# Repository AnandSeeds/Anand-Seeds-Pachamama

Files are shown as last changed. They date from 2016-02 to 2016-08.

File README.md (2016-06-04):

# Sistema de versionamiento AnandSeeds
## Proyecto Piloto - [SIE (Sistema de Innovación Ecológico) Cultivando Futuro!!!](http://anandseeds.co/index.php) 

Desarrollamos e implementamos soluciones TI relacionadas con IoT (Internet of Things), Big Data y Cloud Computing dirigidas al sector agropecuario y agroindustrial. Anand Seeds le permite crear una red de monitoreo integral de los parámetros agroclimáticos para alertar eventos y garantizar mejores cosechas. En nuestro equipo, entendemos que los problemas de cada productor son distintos y es por eso que trabajamos en entregar un set de información integral para el desarrollo del cultivo.

## Hardware Top
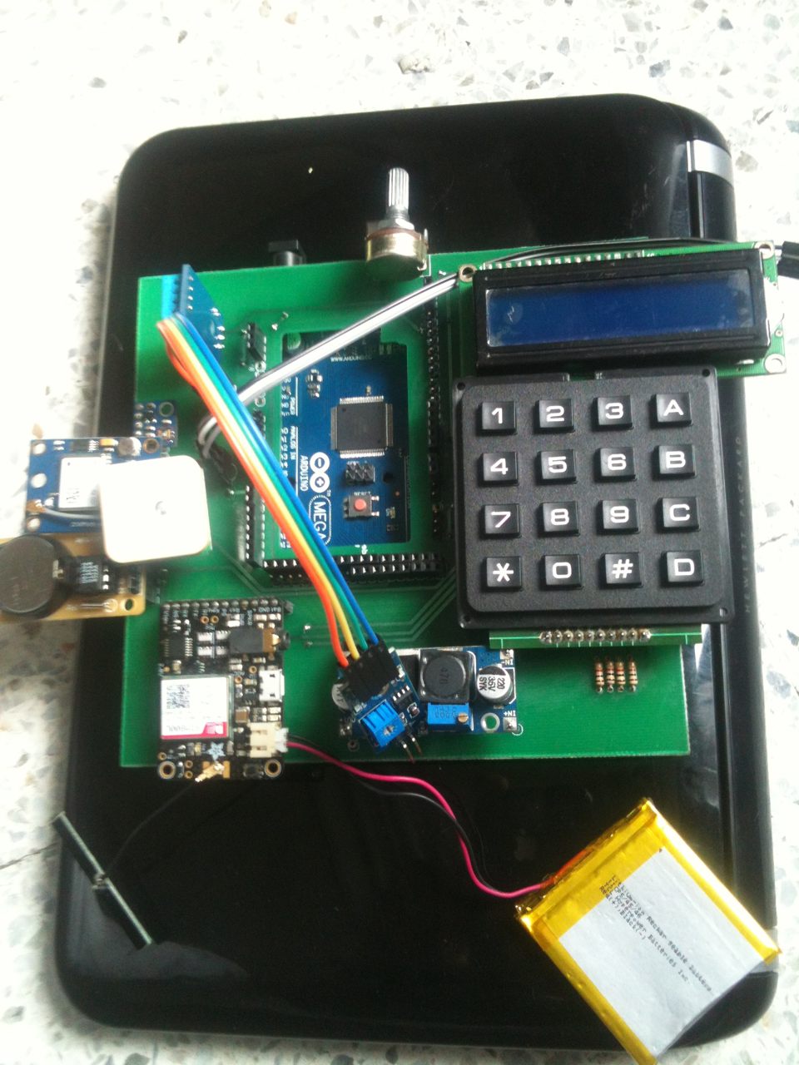
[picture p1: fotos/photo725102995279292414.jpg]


## Hardware Bottom
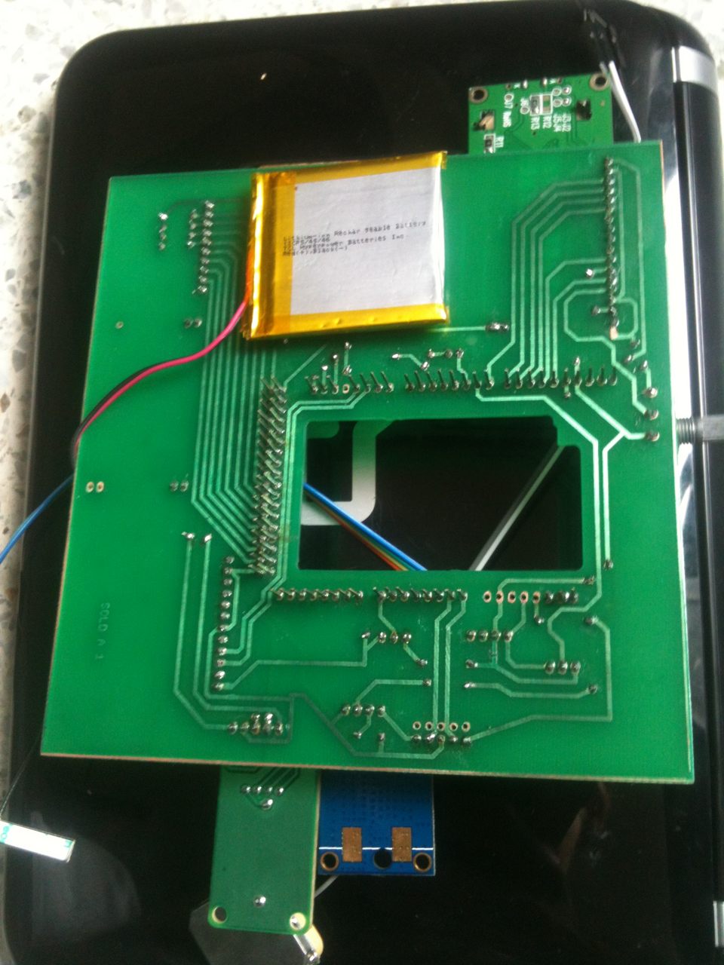
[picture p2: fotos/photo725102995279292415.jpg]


### INFORMACIÓN DE CONTACTO DESARROLLADORES ###
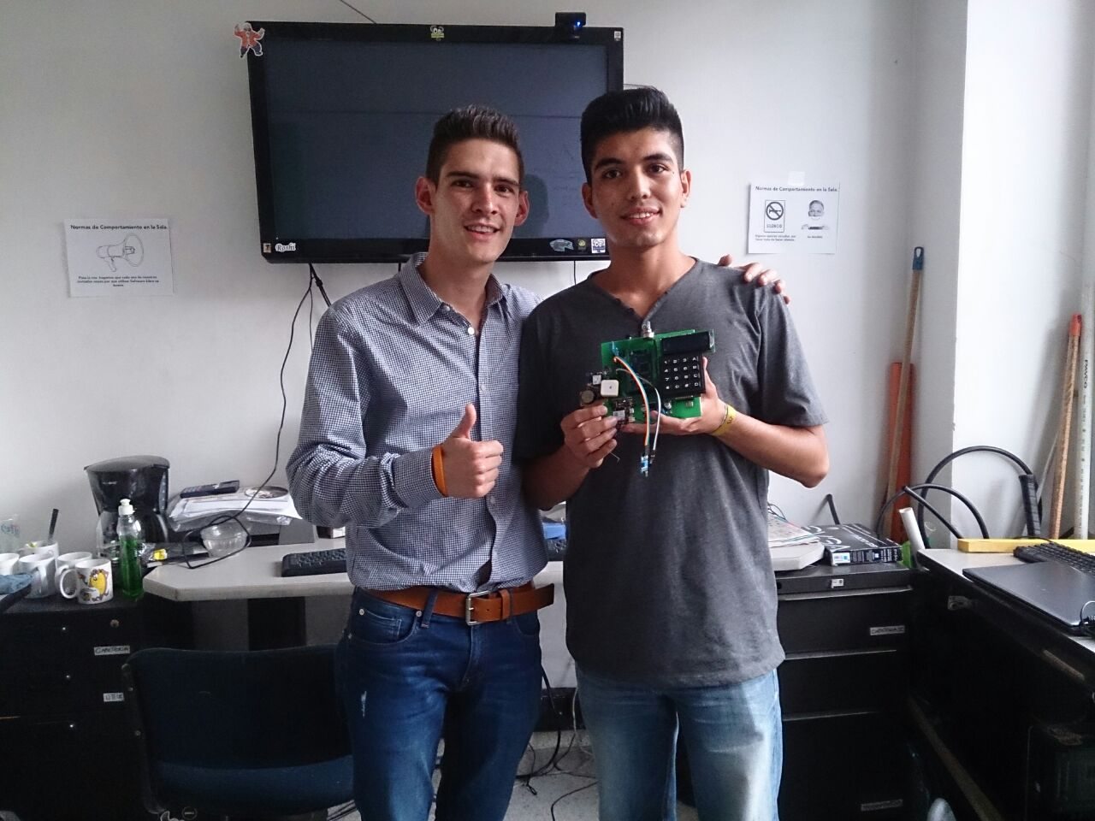
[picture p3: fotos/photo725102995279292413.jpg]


* Desarrollador: Jorge Ulises Useche Cuellar  
Est.Ingeniería Electónica de la Udistrital FJC  
E-mail: naturalmentejorge@gmail.com  
Movil: 3114813719    
Facebook: Jorge Ulises    
Twitter: @juusechec    

* Desarrollador: Diego Javier Mena Amado   
Est. Ingeniería Electrónica de la UDistrital FJC   
E-mail: ingelectronicadj@gmail.com  
Movil: 3133067541   
Facebook: Diego Javier Brown  
Twitter: @ DiegoJavierMena

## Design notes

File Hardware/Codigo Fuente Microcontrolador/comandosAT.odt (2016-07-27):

COMANDO | SALIDA | DESCRIPCION
AT+CBC | +CBC: 0,84,4075 OK | Retorna el estado de la bateria del dispositivo (porcentaje 0,84; milivol 4075)
AT+IPR=9600 | OK | Configura la tasa de baudios para el FONA
AT+CSQ | +CSQ: 15,0 OK | Retorna la calidad de la señal que depende de la antena y la localizacion
AT+CREG=1 | OK | Verifica si la simcard a sido o no registrada
AT+CIPSHUT | SHUT OK | Resetea las direcciones IP
AT+CGATT=1 | OK | Verifica si el gprs esta activo o no
AT+CIPSTATUS | OK STATE: IP INITIAL | Verifica si la pila o stack IP es inicializada
AT+CIPMUX=0 | OK | Esta la conexión en modo simple(udp/tcp cliente o tcp server)
-------GPS-------
AT+CMGF=1 | OK
AT+CGATT=1 | OK
AT+SAPBR=3,1,"CONTYPE","GPRS" | OK
AT+SAPBR=3,1,"APN","your apn here" Ejemplo: Para Sim Card Claro AT+SAPBR=3,1,"APN","internet.comcel.com.co" | OK
AT+SAPBR=1,1 | OK (Red Blink Faster)
AT+CIPGSMLOC=1,1
------Para llamar-------
ATD+573133067541; | OK NO CARRIER | Para llamar
ATH | OK | Para colgar

- First we setup the GPRS:
  - AT+CMGF=1
  - AT+CGATT=1
  - AT+SAPBR=3,1,"CONTYPE","GPRS"
  - AT+SAPBR=3,1,"APN","your apn here"
  - AT+SAPBR=1,1
- The we setup HTTP and make the request
  - AT+HTTPINIT
  - AT+HTTPPARA=”CID”,1
  - AT+HTTPPARA=”URL”,”your url here”
  - AT+HTTPACTION=0
  - AT+HTTPREAD
- Then we close the HTTP and the GPRS
  - AT+HTTPTERM
  - AT+SAPBR=0,1

Hilo de comandos AT: https://learn.adafruit.com/adafruit-fona-mini-gsm-gprs-cellular-phone-module/wiring-to-usb

Hilo para configurar APN's faltantes: https://www.colombiandroid.com/general/guia-para-configurar-apn-de-operadores-colombianos-tigo-claro-y-movistar/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

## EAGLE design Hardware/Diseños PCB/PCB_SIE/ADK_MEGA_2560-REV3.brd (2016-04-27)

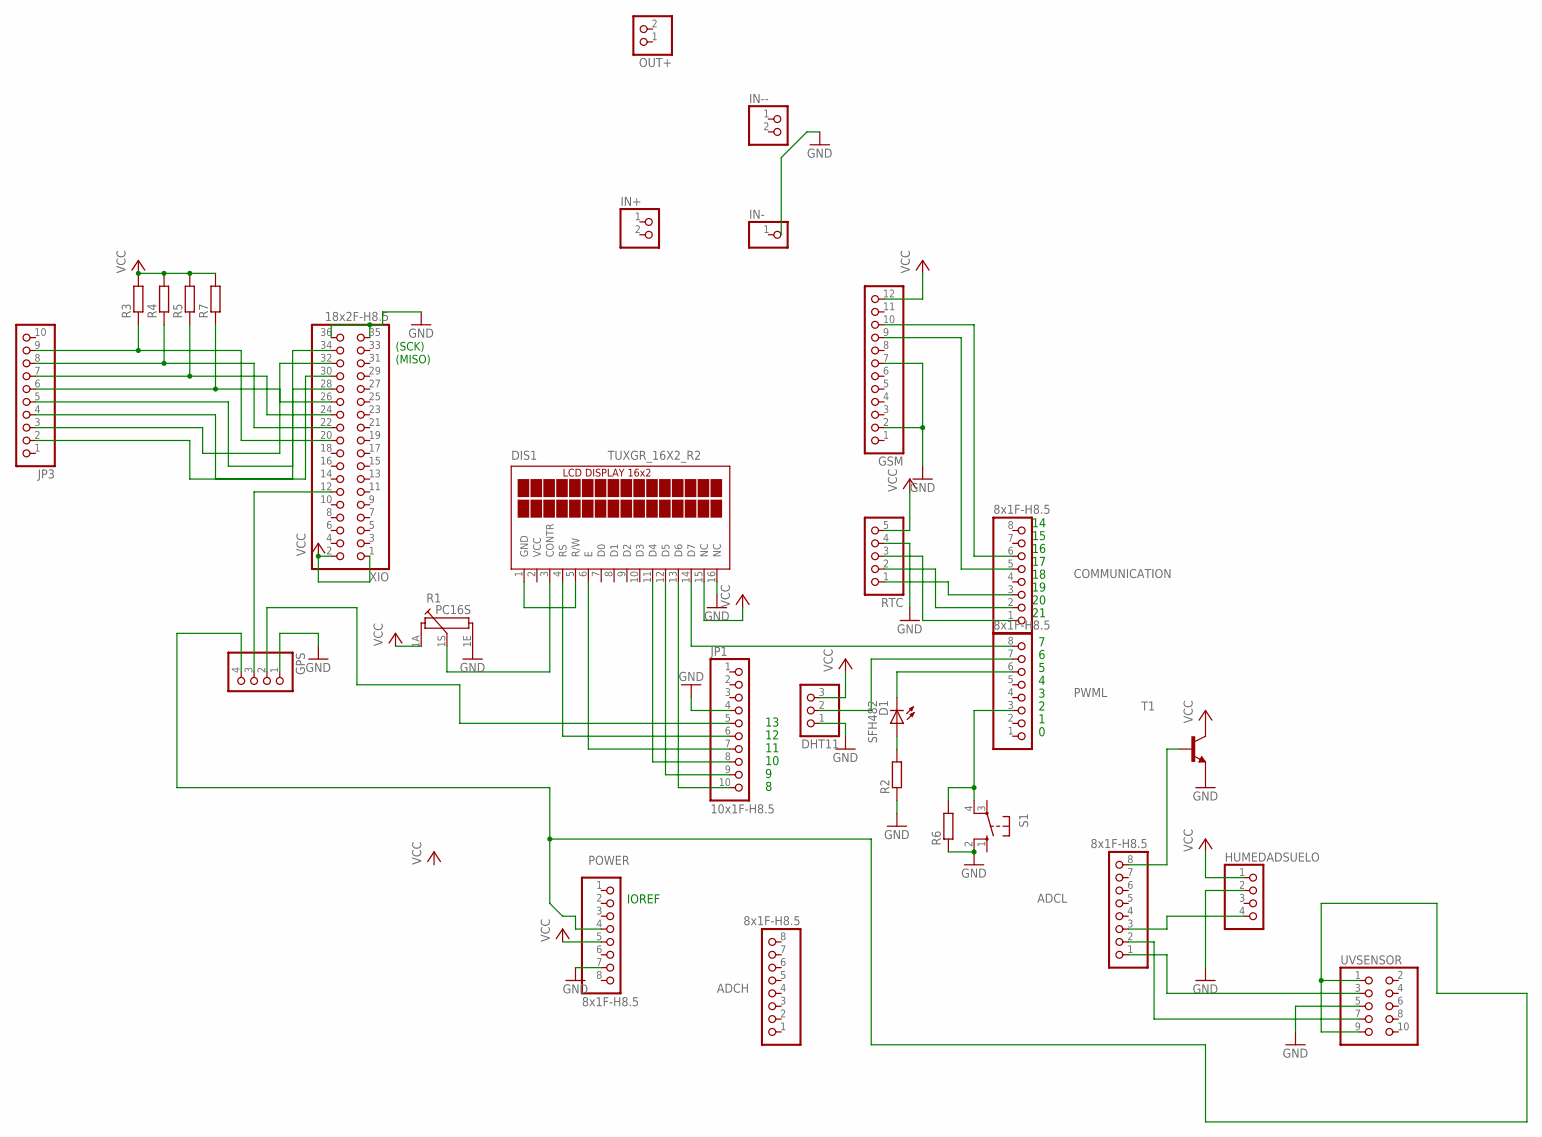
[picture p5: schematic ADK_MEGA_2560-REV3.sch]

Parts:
ADCH: 8x1F-H8.5; 1X08
ADCL: 8x1F-H8.5; 1X08
COMMUNICATION: 8x1F-H8.5; 1X08
D1: SFH482
DHT11: PINHD-1X3; 1X03
DIS1: TUXGR_16X2_R2
GPS: PINHD-1X4; 1X04
GSM: PINHD-1X12; 1X12
HUMEDADSUELO: PINHD-1X4; 1X04
IN+: PINHD-1X2; 1X02
IN-: PINHD-1X1; 1X01
IN--: PINHD-1X2; 1X02
JP1: 10x1F-H8.5; 1X10
JP3: PINHD-1X10/90; 1X10/90
OUT+: PINHD-1X2; 1X02
POWER: 8x1F-H8.5; 1X08
PWML: 8x1F-H8.5; 1X08
R1: PC16S
R2, R3, R4, R5, R6, R7: R0204/7; 0204/7
RTC: PINHD-1X5; 1X05
S1: 10-XX; B3F-10XX
T1: 2N2222-NPN-TO92-EBC; TO92-EBC
UVSENSOR: PINHD-2X5; 2X05
XIO: 18x2F-H8.5; 2X18

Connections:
GND: DHT11.1, DIS1.16 (NC), GPS.1, GSM.2, GSM.7, HUMEDADSUELO.2, JP1.4, POWER.7, R1.1E, R2.1, R6.1, RTC.4, S1.2 (S1), T1.E, UVSENSOR.5, XIO.35, XIO.36
unnamed: DIS1.3 (CONTR), R1.1S
unnamed: D1.K (C), PWML.6
unnamed: D1.A, R2.2
unnamed: DIS1.14 (D7), PWML.8
unnamed: DIS1.1 (GND), DIS1.5 (R/W)
unnamed: DIS1.13 (D6), JP1.10
unnamed: DIS1.12 (D5), JP1.9
unnamed: DIS1.11 (D4), JP1.8
unnamed: DIS1.6 (E), JP1.7
unnamed: DIS1.4 (RS), JP1.6
unnamed: GPS.2, JP1.5
unnamed: DHT11.2, PWML.7
unnamed: GPS.3, XIO.12
unnamed: COMMUNICATION.1, RTC.3
unnamed: COMMUNICATION.2, RTC.2
unnamed: COMMUNICATION.3, RTC.1
unnamed: ADCL.3, HUMEDADSUELO.4
unnamed: ADCL.8, T1.B
unnamed: ADCL.2, UVSENSOR.7
unnamed: ADCL.1, UVSENSOR.3
unnamed: PWML.3, R6.2, S1.4 (P1)
unnamed: COMMUNICATION.6, GSM.10
unnamed: COMMUNICATION.5, GSM.9
unnamed: JP3.9, R3.1, XIO.20
unnamed: JP3.8, R4.1, XIO.22
unnamed: JP3.7, R5.1, XIO.24
unnamed: JP3.6, R7.1, XIO.26
unnamed: GPS.4, POWER.4, UVSENSOR.1, UVSENSOR.9
unnamed: JP3.5, XIO.28
unnamed: JP3.4, XIO.30
unnamed: JP3.3, XIO.32
unnamed: JP3.2, XIO.34
VCC: DHT11.3, DIS1.2 (VCC), DIS1.15 (NC), GSM.12, HUMEDADSUELO.1, POWER.5, R1.1A, R3.2, R4.2, R5.2, R7.2, RTC.5, T1.C, XIO.1, XIO.2

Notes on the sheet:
(SCK)
(MISO)
IOREF

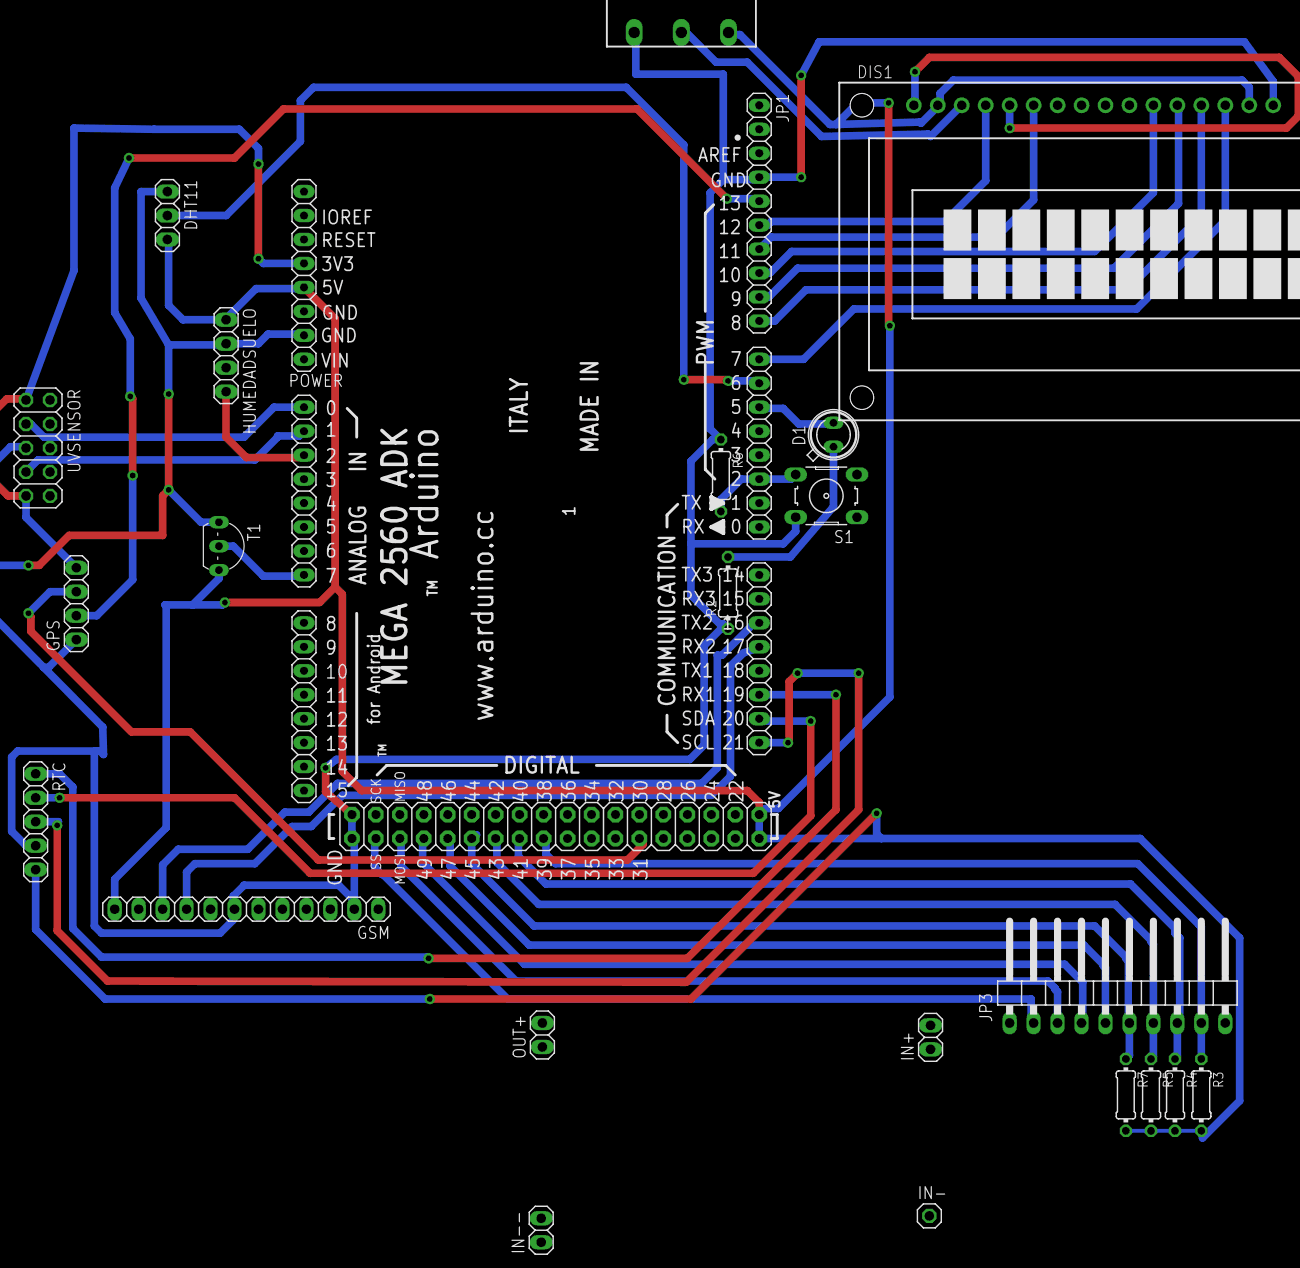
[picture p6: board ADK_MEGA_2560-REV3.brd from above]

Board: 2 copper layers, 29 parts (0 on the bottom side), 34 nets.

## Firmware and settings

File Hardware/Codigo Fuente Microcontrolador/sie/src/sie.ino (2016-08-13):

#include <Arduino.h>

/*
 ***********************************************************************
 *              LIBRERIAS y CONSTANTES
 ***********************************************************************
 */

/****** INICIO MODULO RELOJ ******/
#include <virtuabotixRTC.h> //
// Creation of the Real Time Clock Object
virtuabotixRTC myRTC(21, 20, 19); // CLK,DAT,RST -- SCLK -> 21, I/O -> 20, CE -> 19
/****** FIN MODULO RELOJ ******/

/***** INICIO KEYBOARD *****/
#include <Keypad.h>
const byte ROWS = 4; // four rows
const byte COLS = 4; // three columns

char keys[ROWS][COLS] = { { '1', '2', '3', 'A' }, { '4', '5', '6', 'B' }, { '7',
    '8', '9', 'C' }, { '*', '0', '#', 'D' } };

byte rowPins[ROWS] = { 45, 43, 41, 39 }; // connect to the row pinouts of the keypad
byte colPins[COLS] = { 53, 51, 49, 47 }; // connect to the column pinouts of the keypad

Keypad keypad = Keypad(makeKeymap(keys), rowPins, colPins, ROWS, COLS);

int posicion = 0;
const char clave[] = "A";
const int tamannoClave = strlen(clave);
char passin[tamannoClave - 1]; //indice 3 denota 4 elementos 0,1,2,3...
int ledLogin = 5;
int intentos = 10;
/***** FIN KEYBOARD *****/

/***** INICIO LCD ******/
#include <LiquidCrystal.h>
LiquidCrystal lcd(12, 11, 10, 9, 8, 7); // LiquidCrystal(rs, enable, d4, d5, d6, d7)
/***** FIN LCD ******/

/***** INICIO MODULO GPS ******/
#define GPS_TX_DIGITAL_OUT_PIN 13
#define GPS_RX_DIGITAL_OUT_PIN 31

#include <SoftwareSerial.h>
SoftwareSerial gpsSerial(13, 31); // RX placa <- TX sensor, TX placa -> RX senxor

#include "TinyGPS.h"
TinyGPS gps;

#define MAX_BUFFER 500

unsigned long momento_anterior = 0;
unsigned long bytes_recibidos = 0;

long startMillis;
long secondsToFirstLocation = 0;

float latitude = 204.0;
float longitude = 269.0;

char latit[12];
char longi[12];
/***** FIN MODULO GPS ******/

/****** INICIO HUMEDAD Y TEMPERATURA AMBIENTE ******/
#include "DHT.h"
#define DHTPIN 6
#define DHTTYPE DHT11 // DHT 22 / 11 (AM2302)
DHT dht(DHTPIN, DHTTYPE);
float h;
float t;
/****** FIN HUMEDAD Y TEMPERATURA AMBIENTE ******/

/******* INICIO TEMPERATURA DEL SUELO **********/
int temp_pin = A7;
float TempC;
/******* FIN TEMPERATURA DEL SUELO **********/

/******* INICIO HUMEDAD DEL SUELO **********/
float HS;
/******* FIN HUMEDAD DEL SUELO **********/

/****** INICIO UV ******/
int uvLevel;
int refLevel;
float outputVoltage;
float uvIntensity;

// Hardware pin definitions MP8511
int UVOUT = A0; // Output from the sensor
int REF_3V3 = A1; // 3.3V power on the Arduino board
/****** FIN UV ******/

/****** INICIO MODULO GSM/GPRS ******/
#include <SoftwareSerial.h>
SoftwareSerial sim800l(17, 16); //RX - TX
String operadorAPN = "";
/****** FIN MODULO GSM/GPRS ******/

/****** INICIO VOLTIMETRO ******/
int pinSonda = A6;
float escala = 0.1; //100 para voltios, 0.1 para milivoltios
/****** FIN VOLTIMETRO ******/

/****** INICIO FUNCIONES ADICIONALES SETUP******/
void configurarLCD() {
  lcd.begin(16, 2);
}

void mensajeCargando() {
  lcd.clear();
  lcd.print("....Cargando....");
}

void mensajeBienvenida() {
  char *mensaje1 = (char*) "    Bienvenido a SIE    ";
  char *mensaje2 = (char*) "    Cultivando Futuro.  ";
  mostrarMensajesAutoscroll(mensaje1, mensaje2);
}

void validarAccesoPorClave() {
  pinMode(ledLogin, OUTPUT); //Iniciar estado led
  lcd.clear();
  Serial.println("Ingresa Clave:");
  lcd.print("Ingresa Clave:");
  while (!ingresarClave()) {
  }
}

/*
 *  Funcion para mostrar mensaje autoScroll en 2 filas con funcion CallBack
 */
void mostrarMensajesAutoscrollConFuncion(const char mensaje[],
    const char mensaje2[], bool (*fun)()) {
  //El mensaje1 y el mensaje 2 deben ser del mismo tamaño
  const int tamannoOp = strlen(mensaje2) - 1;
  int ancho = 15; //El número de columnas del LCD son 16 menos 1 = 15

  VOLVERAMOSTRAR: int barrido = 0;

  while (barrido <= tamannoOp - ancho) {
    for (int positionCounter = barrido; positionCounter <= ancho + barrido;
        positionCounter++) {
      lcd.setCursor(positionCounter - barrido, 0);
      lcd.print(String(mensaje[positionCounter]));
      lcd.setCursor(positionCounter - barrido, 1);
      lcd.print(String(mensaje2[positionCounter]));
      bool siTecla = (*fun)();
      if (siTecla) {
        return;
      }
    }
    barrido++;
    int temporizador = 150;
    while (temporizador > 0) {
      bool siTecla = (*fun)();
      if (siTecla) {
        return;
      }
      temporizador--;
    }
    lcd.clear();
  }

  goto VOLVERAMOSTRAR;
}

/*
 *  Funcion mensaje
 */
void ingresarAPN() {
  const char mensaje[] = "   Ingresa Operador Movil:              Ingresa Operador Movil:         "; //El mensaje y el operador deben ser del mismo tamaño
  const char operador[] = "   1-CLARO 2-MOVISTAR 3-VIRGIN 4-TIGO 5-UFF 6-UNE 7-ETB 8-EXITO 9-AVANTEL";
  mostrarMensajesAutoscrollConFuncion(mensaje, operador,detectarTeclaOperador);
}

/*
 *  Funcion para seleccionar operadorAPN por teclado matricial
 */
 bool detectarTeclaOperador() {
   char key = keypad.getKey();
   Serial.println(String(key));
   //Números del 1 al 3
   if (key) {
     switch (key) {
     case '1':
       operadorAPN =
           String(
               "AT+CSTT=\"internet.comcel.com.co\",\"COMCELWEB\",\"COMCELWEB\"");
       Serial.println("Configurando APN Claro");
       break;
     case '2':
       operadorAPN =
           String(
               "AT+CSTT=\"internet.movistar.com.co\",\"movistar\",\"movistar\"");
       Serial.println("Configurando APN Movistar");
       break;
     case '3':
       operadorAPN = String("AT+CSTT=\"web.vmc.net.co\",\"\",\"\"");
       Serial.println("Configurando APN Virgin Mobile");
       break;
     case '4':
       operadorAPN = String("AT+CSTT=\"web.colombiamovil.com.co\",\"\",\"\"");
       Serial.println("Configurando APN TIGO");
       break;
     case '5':
       operadorAPN = String("AT+CSTT=\"web.uffmovil.com\",\"\",\"\"");
       Serial.println("Configurando APN UFF");
       break;
     case '6':
       operadorAPN = String("AT+CSTT=\"www.une.net.co\",\"une\",\"une\"");
       Serial.println("Configurando APN UNE");
       break;
     case '7':
       operadorAPN = String("AT+CSTT=\"moviletb.net.co\",\"etb\",\"etb\"");
       Serial.println("Configurando APN ETB");
       break;
     case '8':
       operadorAPN = String("AT+CSTT=\"movilexito.net.co\",\"\",\"\"");
       Serial.println("Configurando APN EXITO");
       break;
     case '9':
       operadorAPN = String("AT+CSTT=\"lte.avantel.com.co\",\"\",\"\"");
       Serial.println("Configurando APN TIGO");
       break;


     default:
       return false;
       break;
     }
     return true;
   } else {
     return false;
   }
 }


void configurarMonitorSerial() {
  Serial.begin(9600);
  Serial.println("Iniciando...");
}

void configurarRTC() {
  myRTC.setDS1302Time(00, 14, 23, 2, 31, 5, 2016); // seg, min, hora, dia de la semana, dia del mes, mes, año
}

void configurarSensorDHT() {
  dht.begin(); //Sensor temperatura y humedad
}

void configurarGPS() {
  pinMode(GPS_TX_DIGITAL_OUT_PIN, INPUT);
  pinMode(GPS_RX_DIGITAL_OUT_PIN, INPUT);
  gpsSerial.begin(9600);
}

/**
 * Realiza la lectura del buffer del módulo GSM, acumula la salida de
 * caracteres hasta que la transmisión serial termina
 * Acumulador de caracteres recursivo
 */
char *debugGSM() { // devuelve el ``contenido de un objeto apuntado por un apuntador''.
  int i = 0;
  static char cad[255] = "\0";
  char c = '\0';
  strcpy(cad, "");
  while (sim800l.available() > 0) {
    c = sim800l.read();
    cad[i] = c;
    i++;
  }
  return cad;
}

/**
 * Se configura el módulo GSM
 */
void configurarGPRS() {
  sim800l.begin(19200);//Configuracion de puerto serial del modulo (baudios por segundo)

  // pinMode(53, OUTPUT);
  Serial.println("Iniciando configuracion del modulo GSM");
  sim800l.println(F("AT"));
  delay(500);
  Serial.println(debugGSM());
  sim800l.println(F("AT+CBC"));//Retorna el estado de la bateria del dispositivo, el % y milivol
  delay(500);
  Serial.println(debugGSM());
  sim800l.println(F("AT+IPR=19200"));//Retorna el estado de la bateria del dispositivo, el % y milivol
  delay(500);
  Serial.println(debugGSM());

  sim800l.println(F("AT+CSQ"));// Retorna la calidad de la señal que depende de la antena y la localizacion
  delay(500);
  Serial.println(debugGSM());

  sim800l.println(F("AT+CREG=1"));// Verifica si la simcard a sido o no registrada
  Serial.println(debugGSM());
  delay(500);
  sim800l.println(F("AT+CIPSHUT"));// Resetea las direcciones IP
  Serial.println(debugGSM());
  delay(500);
  sim800l.println(F("AT+CGATT=1"));// Verifica si el gprs esta activo o no
  Serial.println(debugGSM());
  delay(500);
  sim800l.println(F("AT+CIPSTATUS"));//Verifica si la pila o stack IP es inicializada
  Serial.println(debugGSM());
  delay(500);
  sim800l.println(F("AT+CIPMUX=0"));//Esta la conexión en modo simple(udp/tcp cliente o tcp server)
  Serial.println(debugGSM());
  delay(500);

  // Configurar tarea y configura el APN
  sim800l.println(operadorAPN);
  Serial.println(debugGSM());
  delay(500);

  sim800l.println(F("AT+CIICR"));// Levantar conexión wireless(GPRS o CSD)
  Serial.println(debugGSM());
  delay(500);

}

/*
 ***********************************************************************
 *              SETUP CONFIGURACIÓN INICIAL
 ***********************************************************************
 */
void setup() {
  configurarMonitorSerial();
  configurarLCD();
  mensajeBienvenida();
  validarAccesoPorClave();
  ingresarAPN();
  mensajeCargando();
  configurarGPRS();
  configurarRTC();
  configurarGPS();
  configurarSensorDHT();
}

/****** INICIO FUNCIONES ADICIONALES LOOP******/

/*
 *  Funcion para el sensado de baterias
 */
void sensarEstadoBateria(void) {
  float lectura = analogRead(pinSonda);
  lectura = map(lectura, 0, 1023, 0, 500);
  float voltaje = lectura / escala;
  //voltaje = 3100.01; //para probarlo
  if (voltaje < 3400) {
    char *mensaje1 = (char*) "    Nivel de carga baja,    ";
    char *mensaje2 = (char*) "    Cargue el dispositivo.  ";
    mostrarMensajesAutoscroll(mensaje1, mensaje2);
    if (voltaje < 3200) {
      char *mensaje = (char*) "    NIVEL CRITICO DE BATERIA    ";
      mostrarMensajeAutoscroll(mensaje);
      sensarEstadoBateria();
    }
  }
}

/*
 *  Funcion para obtener Fecha y Hora con el uso de la RTC
 */
void GetTimeRTC() {
  myRTC.updateTime();
  // Delay so the program doesn't print non-stop
  delay(5000);
}

/**
 * Se utiliza para cargar los datos del modulo GPS y se guardan en las variables
 * globales latit y longi.
 */
void GetGPS() {
  bool newData = false;
  unsigned long chars = 0;
  unsigned short sentences, failed;

  for (unsigned long start = millis(); millis() - start < 1000;) {
    while (gpsSerial.available()) {
      int c = gpsSerial.read();
      ++chars;
      if (gps.encode(c)) {
        newData = true;
      }
    }
  }

  if (newData) {
    if (secondsToFirstLocation == 0) {
      secondsToFirstLocation = (millis() - startMillis) / 1000;
    }
    unsigned long age;
    gps.f_get_position(&latitude, &longitude, &age);
    Serial.print("Location: ");
    Serial.print(latitude, 6);
    Serial.print(" , ");
    Serial.print(longitude, 6);
    Serial.println("");
  }
  dtostrf(latitude, 0, 6, latit);
  dtostrf(longitude, 0, 6, longi);
  Serial.println(latit);
  Serial.println(longi);
}

/**
 * Se obtiene la humedad relativa (aire) y se guarda en las variables globales h y t.
 */
void GetHT() {
  h = dht.readHumidity();
  t = dht.readTemperature();
}

/**
 * Se obtiene la temperatura por medio de la lectura analoga del pin temp_pin
 */
void GetTs() {
  TempC = analogRead(temp_pin);
  TempC = (5.0 * TempC * 100.0) / 1024.0;
}

/**
 * Se optiene la humedad del suelo por medio del PIN analogo A2.
 */
void GetHS() {
  int val2 = analogRead(A2);
  HS = val2 * (5.0 / 1023.0);
}

/**
 * Se obtiene la radiacion ultravioleta y se guarda en la variable global uvIntensity.
 */
void GetUV() {
  uvLevel = averageAnalogRead(UVOUT);
  refLevel = averageAnalogRead(REF_3V3);

  // Use the 3.3V power pin as a reference to get a very accurate output
  // value from sensor
  outputVoltage = 3.3 / refLevel * uvLevel;
  uvIntensity = mapfloat(outputVoltage, 0.99, 2.9, 0.0, 15.0); // (mW/cm^2)
}

/**
 * Se imprimen los registros de:
 * Humedad Relativa
 * Temperatura
 * Humedad del Suelo
 * Temperatura del Suelo
 * Se espera 3 segundo para que se mantengan los datos.
 */
void mostrarRegistros() {
  lcd.clear();
  lcd.setCursor(0, 0);
  lcd.print("H:");
  lcd.print(h);
  lcd.setCursor(0, 1);
  lcd.print("T:");
  lcd.print(t);
  lcd.setCursor(9, 0);
  lcd.print("Hs:");
  lcd.print(HS);
  lcd.setCursor(9, 1);
  lcd.print("Ts:");
  lcd.print(TempC);
  delay(3000);
}

/**
 * Se imprimen los datos:
 * Nivel UV
 * Intensidad UV
 * Y se esperan 3 segundos.
 */
void mostrarRegistros2() {
  lcd.clear();
  lcd.setCursor(0, 0);
  lcd.print("UV level:");
  lcd.print(uvLevel);
  lcd.setCursor(0, 1);
  lcd.print("UV Inten:");
  lcd.print(uvIntensity);
  delay(3000);
}

/**
 * Se imprime en el LCD la latitud y longitud dadas por el GPS
 */
void mostrarRegistros3() {
  lcd.clear();
  lcd.setCursor(0, 0);
  lcd.print("La:");
  lcd.print(latit);
  lcd.setCursor(0, 1);
  lcd.print("Lo:");
  lcd.print(longi);
  delay(3000);
}

/**
 * Para información del usuario en el LCD se imprime la fecha y la hora.
 */
void mostrarFecha() {
  // DateTime now = RTC.now();
  lcd.clear();
  lcd.setCursor(0, 0);
  lcd.print("FECHA:");
  lcd.print(myRTC.dayofmonth);
  lcd.print("/");
  lcd.print(myRTC.month);
  lcd.print("/");
  lcd.print(myRTC.year);
  lcd.setCursor(0, 1);
  lcd.print("HORA:");
  lcd.print(myRTC.hours);
  lcd.print(":");
  lcd.print(myRTC.minutes);
  lcd.print(":");
  lcd.print(myRTC.seconds);
  delay(3000);
}

/**
 * Funcion para promedio de muestreo
 * @param int pinToRead el puerto análogo que se debe leer
 * @return int se obtiene el promedio de las últimas 8 muestras tomadas en el pin
 */
int averageAnalogRead(int pinToRead) {
  byte numberOfReadings = 8;
  unsigned int runningValue = 0;

  for (int x = 0; x < numberOfReadings; x++)
    runningValue += analogRead(pinToRead);
  runningValue /= numberOfReadings;

  return (runningValue);
}

/**
 * Arreglo para mapeo de punto flotante UVSensor
 * The Arduino Map function but for floats
 * From: http://forum.arduino.cc/index.php?topic=3922.0
 * https://learn.sparkfun.com/tutorials/ml8511-uv-sensor-hookup-guide
 * @param float x es el voltaje de salida del sensor
 * @param float in_min es un voltaje de 0.99V
 * @param float in_max es un voltaje de 2.8V
 * @param float out_min es el minimo nivel de radiación UV
 * @param float out_max es el maximo nivel de radiación UV
 * @return float que representa el nivel de radiación UV
 */
float mapfloat(float x, float in_min, float in_max, float out_min,
    float out_max) {
  return (x - in_min) * (out_max - out_min) / (in_max - in_min) + out_min;
}

/**
 * Se acitva si el peso se encuentra en un limite definido
 */
void enviarDatosSIM() {
  lcd.clear();
  if(latitude==204&&longitude==269){
    char *mensaje = (char*) "    GPS NO disponible...    ";
    mostrarMensajeAutoscroll(mensaje);
    GetGPS();
    enviarDatosSIM();
    return;
  } else {
    lcd.print("Enviando Datos...");
  }

  //Se acitva si el peso se encuentra en un limite definido
  //sim800l.println(F("AT+CIPSHUT")); //Resetea las direcciones IP
  //Serial.println(debugGSM());
  //delay(500);
  sim800l.println("AT+CIFSR"); // Obtiene una dirección IP
  Serial.println(debugGSM());
  delay(2000);

  sim800l.println(F("AT+CIPSTART=\"TCP\",\"107.170.208.9\",\"8080\"")); //Inicia conexión UDP o TCP
  Serial.println(debugGSM());
  delay(2000);

  //Visualización transparente pero no funciona
  //sim800l.println(F("AT+CIPMODE=1")); //Inicia conexión UDP o TCP
  //Serial.println(debugGSM());
  //delay(2000);

  sim800l.println(F("AT+CIPSEND\r\n")); // Envia datos al servidor remoto, ctlr+z o 0x1A,
  //verifica que los datos salieron del puerto serial pero no indica si llegaron al servidor UDP
  Serial.println(debugGSM());
  delay(2000);

  static char ts[15];
  dtostrf(TempC, 0, 3, ts); // dtostrf(var, characters long, characters after the decimal point,array to save)
  static char ta[15];
  dtostrf(t, 0, 3, ta);
  static char hs[15];
  dtostrf(HS, 0, 3, hs);
  static char hr[15];
  dtostrf(h, 0, 3, hr);
  static char iuv[15];
  dtostrf(uvIntensity, 0, 3, iuv);
  String cadena =
      "GET /index.php?data=0Ihzhj0geg_u16zk9AJNLlGl9F-9kE_bxeocU3n_RBOoDc-di1h93jvWz6chN9zBuF78S7NlmsMoYCF7NQ4-MeD5sqbkKWcF1onSaZz8EI-ABc1Ej1tNL-HMdr2YJS-N&id=1&ts="
          + String(ts) + "&ta=" + String(ta) + "&hs=" + String(hs)
          + "&hr=" + String(hr) + "&nuv=" + String(uvLevel) + "&iuv="
          + String(iuv) + "&lat=" + String(latit) + "&lon="
          + String(longi);
  Serial.println(cadena);
  sim800l.println(cadena);
  Serial.println(debugGSM());
  delay(2000);

  pushSlow((char*) "\r\n", 100, 100); //Envia un salto de linea
  pushSlow((char*) "\x1A", 100, 100); //ctlr+z para finalizar el envio o 0x1A
  //sim800l.write(0x1A);//ctlr+z para finalizar el envio o 0x1A
  Serial.println(debugGSM());
  delay(2000);

  sim800l.println(F("AT+CIPSHUT")); //Resetea las direcciones IP
  Serial.println(debugGSM());

  lcd.clear();
  lcd.print("Datos Enviados");
}

/**
 * Envia datos por el SoftSerial lentamente
 */
void pushSlow(char* command, int charaterDelay, int endLineDelay) {
  for (int i = 0; i < strlen(command); i++) {
    sim800l.write(command[i]);
    if (command[i] == '\n') {
      delay(endLineDelay);
    } else {
      delay(charaterDelay);
    }
  }
}

/*
 *  Funcion acceso por teclado matricial
 */
boolean ingresarClave() {
  char key = keypad.getKey();
  if (key) {
    if (posicion == tamannoClave - 1) {
      lcd.setCursor(posicion, 1);
      passin[posicion] = key;
      // print the number of seconds since reset:
      lcd.print(key);
      boolean iguales = true;
      for (int i = 0; i < strlen(clave); i++) {
        if (passin[i] == clave[i]) {
          iguales = iguales && true;
        } else {
          iguales = iguales && false;
        }
      }
      if (iguales) {
        lcd.setCursor(0, 0);
        lcd.print("Ingreso Correcto");
        lcd.setCursor(0, 1);
        lcd.print("        ");
        digitalWrite(ledLogin, HIGH);
        return true;
      } else {
        lcd.setCursor(0, 0);
        lcd.print("Intenta de nuevo...");
        lcd.setCursor(0, 1);
        lcd.print("           ");

        if (intentos <= 0) {
          while (true) {
            mostrarMensajeAutoscroll(
                (char*) "    Reinicie el sistema    ");
          }
        } else {
          intentos--;
          posicion = 0;
        }
      }
    } else {
      lcd.setCursor(posicion, 1);
      // print the number of seconds since reset:
      lcd.print(key);
      passin[posicion] = key;
      posicion++;
    }
  }
  return false;
}

/**
 * Permite configurar la visualizacion de variables
 */
void visualizarVariablesSerial() {
  Serial.print("FECHA:");
  Serial.print(myRTC.dayofmonth);
  Serial.print("/");
  Serial.print(myRTC.month);
  Serial.print("/");
  Serial.println(myRTC.year);
  Serial.print("HORA:");
  Serial.print(myRTC.hours);
  Serial.print(":");
  Serial.print(myRTC.minutes);
  Serial.print(":");
  Serial.println(myRTC.seconds);
  Serial.println("Humedad:");
  Serial.println(h);
  Serial.println("Temperatura:");
  Serial.println(t);
  Serial.println("Humedad Suelo:");
  Serial.println(HS);
  Serial.println("Temperatura Suelo:");
  Serial.println(TempC);
  Serial.println("UV level:");
  Serial.println(uvLevel);
  Serial.println("UV Inten:");
  Serial.println(uvIntensity);
  Serial.println("Latitud:");
  Serial.println(latit);
  Serial.println("Longitud:");
  Serial.println(longi);
  Serial.print("Envio de datos finalizado.\r\n");
}

/*
 *  Funcion para mostrar mensaje autoScroll en 1 fila
 */
void mostrarMensajeAutoscroll(char *mensaje) {
  int tamannoOp = strlen(mensaje) - 1;
  int ancho = 15; //El número de columnas del LCD son 16 menos 1 = 15
  int barrido = 0;
  while (barrido <= tamannoOp - ancho) {
    for (int positionCounter = barrido; positionCounter <= ancho + barrido;
        positionCounter++) {
      lcd.setCursor(positionCounter - barrido, 0);
      lcd.print(String(mensaje[positionCounter]));
    }
    barrido++;
    delay(500);
    lcd.clear();
  }
}

/*
 *  Funcion para mostrar mensaje autoScroll en 2 filas
 */
void mostrarMensajesAutoscroll(char *mensaje, char *mensaje2) {
  //El mensaje1 y el mensaje 2 deben ser del mismo tamaño
  const int tamannoOp = strlen(mensaje2) - 1;
  int ancho = 15; //El número de columnas del LCD son 16 menos 1 = 15
  int barrido = 0;

  while (barrido <= tamannoOp - ancho) {
    for (int positionCounter = barrido; positionCounter <= ancho + barrido;
        positionCounter++) {
      lcd.setCursor(positionCounter - barrido, 0);
      lcd.print(String(mensaje[positionCounter]));
      lcd.setCursor(positionCounter - barrido, 1);
      lcd.print(String(mensaje2[positionCounter]));
    }
    barrido++;
    delay(500);
    lcd.clear();
  }
}

/****** FIN FUNCIONES ADICIONALES ******/

/*
 ***********************************************************************
 *              LOOP BUCLE PRINCIPAL
 ***********************************************************************
 */
void loop() {
  sensarEstadoBateria();
  mensajeCargando();
  GetTimeRTC();
  GetGPS();
  GetHT();
  GetTs();
  GetHS();
  GetUV();
  enviarDatosSIM();
  delay(4000);
  visualizarVariablesSerial();
  mostrarFecha();
  mostrarRegistros();//Humedad y Temperatura, Aire y Suelo
  mostrarRegistros2();//Nivel UV e Intensidad UV
  mostrarRegistros3();//Latitud y Longitud
}

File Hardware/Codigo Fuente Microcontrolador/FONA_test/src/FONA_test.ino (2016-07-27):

#include <SoftwareSerial.h>

//PIN FONA Vio = 5V
//PIN FONA GND = GND
#define FONA_RX 3 // Serial RX
#define FONA_TX 4 // Serial TX
#define FONA_RST 5  //resets board
#define FONA_KEY 6 //powers board down
#define FONA_PS 7 //status pin. Is the board on or not?

SoftwareSerial fonaSS = SoftwareSerial(FONA_TX, FONA_RX); //initialize software serial
char inChar = 0;

void setup() {
  pinMode(FONA_PS, INPUT);
  pinMode(FONA_KEY,OUTPUT);
  digitalWrite(FONA_KEY, HIGH);
  Serial.begin(9600);
  Serial.println("Serial Listo");
  fonaSS.begin(9600);
  Serial.println("FONA Serial Listo");
}

void loop() {
  if (fonaSS.available()){
    inChar = fonaSS.read();
    Serial.write(inChar);
    delay(20);
  }
  if (Serial.available()>0){
    fonaSS.write(Serial.read());
  }
}

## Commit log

2016-02-27 Se añaden carpetas para alojar versionamiento de la hack-actividad
2016-02-27 Se añaden carpetas para versionamiento de hardware y web informativa
2016-02-27 Se complementan datasheets de componentes electricos y electronicos
2016-02-27 Agregando la parte de SARA
2016-02-27 Se agregan los bloques de componentes gráficos
2016-02-27 Correcci[on en el inicio de sesión y estilos
2016-02-27 Se agrega código fuente compilando de lectura de sensores
2016-02-27 Se documenta un poco más el código, hay que mejorar la forma en como se explican los métodos.
2016-02-27 Se cambia extensión para que pueda ser leido por arduino
2016-02-27 Se construye una carpeta indispensable para arduino
2016-02-27 Se crean los módulos de registro de usuario y de emplazamiento
2016-02-27 Se añade esquema de conexiones, archivo disponible para Fritzing
    [diagramaConexion.fzz]
2016-02-27 Se agrega servicio web para probar conectividad por GSM
2016-02-27 Se corrigen errores sobre el web service
2016-02-27 Se sube backup de sitio web para presentación
2016-02-27 Transmisión de datos funcionando
2016-02-27 Se añade arreglo de floats en matriz de caracteres para concatenar el envio de datos
    [HackathonAgro.ino]
2016-02-28 Se modifica arreglo para remover espacios y se vinculan variables dinamicas
    [HackathonAgro.ino]
2016-02-28 Se modifica la página de inicio
2016-02-28 Modificación a la página de registro de usuarios
2016-02-28 Se corrige el registro de datos y la consulta
2016-02-28 Se agrega la página de visor de mapas para la ubicación de los dispositivos
2016-02-28 Se añade funcionalidad de acceso a datos por teclado con variables dinamicas
2016-03-13 Se añaden paquetes de conexiones electricas hechas en Fritzing
    [Esquema-Final-A.fzz, Esquema-Final-B.fzz]
2016-03-23 Se hacen arreglos de funcionalidades registro emplazamiento y usuario
2016-03-23 Se suben modificaciones del formulario de acceso y se comprimen librerias del microcontrolador
2016-03-24 Se mejora la legibilidad del código fuente
2016-03-24 Se agrega código de prueba del módulo GPS
2016-03-26 Se añade codigo para seleccionar opciones con el teclado matricial y se sobre-escriben archivos compilados y en funcionamiento
2016-04-01 Se suben archivos de diseño PCB
    [ADK_MEGA_2560-REV3.brd, ADK_MEGA_2560-REV3.sch]
2016-04-27 se añade esquematicos, diseño PCB y archivos gerber para impresion
    [ADK_MEGA_2560-REV3.GBL, ADK_MEGA_2560-REV3.GBO, ADK_MEGA_2560-REV3.GBP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]
2016-04-27 Se modifica la posicion del GPS, se corrijen paths y se distancian sensores
    [ADK_MEGA_2560-REV3.brd]
2016-05-27 Se arreglan los puntos de geolocalización
2016-05-28 Se mejora el servicio web que consulta puntos
2016-05-28 Se corrigen los warnings de la funcion degubGSM y pushSlow
    [sie.ino]
2016-05-28 Se añade auto-scroll para mensajes
2016-05-29 Mensaje de selección de Operador Móvil y Selector de Configuración APN Movistar, Claro y Virgin
2016-05-29 Se reparó servicio web para las gráficas de seguimiento de variables
2016-05-29 Se invierten los parametros de latitud y longitud
2016-05-31 Se arregla sensado de batería
    [sie.ino]
2016-06-01 Se corrige el número de intentos
    [sie.ino]
2016-06-01 Ahora si funcionando de verdad
2016-06-01 Se quita visualización de datos GSM/GPRS transpararente
2016-06-01 No envía datos cuando el GPS no está disponible
2016-06-01 Se mejora funcion enviarDatosSim para que en el momento de obtener coordendas GPS ejecute la funcion enviarDatosSIM
2016-06-04 Se añade la carpeta de fotos para ver el crecimiento
2016-06-04 Se añade una pequeña info para el readme
    :D
2016-06-05 Usando el código con atom
2016-07-25 Se añade codigo fuente para test de comandos AT
2016-07-26 Se añade archivo para la comprensión de los comandos AT empleados hasta el momento y algunos útiles para obtener las coordenadas GPS sin la ayuda del modulo gps implementado hasta el momento
2016-07-27 Se añaden ficheros para compilar el codigo del micro con ATOM y se añaden comandos AT para realizar llamadas telefonicas
2016-08-13 se configura para que funcione con plattform-ide
2016-08-13 Se agregar operadores telefonicos de Colombia
2016-08-13 Se eliminan librerias innecesarias y se deja estable el codigo fuente
